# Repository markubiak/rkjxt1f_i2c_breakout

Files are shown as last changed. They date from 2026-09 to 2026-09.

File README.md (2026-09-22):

Alps RKJXT1F42001 7-Way Switch and Encoder I2C Breakout
-------------------------------------------------------

I2C breakout for Alps RKJXT1F42001 using Adafruit Seesaw library on the SAMD09.
Schematic is a copy of the I2C "Stemma QT" Rotary Encoder breakout board
(product 4991), though the NeoPixel and 2x STEMMA QT (JST SH 4-pin) connectors
had to be dropped due to layout constraints. The RKJXT1F is a significantly
larger through-hole device than the rotary encoder and the Stemma QT connectors
simply would not fit in their original locations. However, identical board
shape (1in x 1in) and mounting holes were retained. Due to an oversight, the
pin ordering in the through-hole connection was flipped from the reference
design.

Pins were kept the same as the reference design, so the firmware built on main
branch of adafruit/seesaw works laregly correctly. There is a difference in how
the RKJXT1F handles the rotary encoding compared to typical encoders, so a fork
of the seesaw library is pushed and pending merge back to main. With the
updated firmware, the I2C protocol works as intended. The GPIO Seesaw registers
can be used for the new A/B/C/D pins.

| Direction | GPIO Number |
|---|---|
| A | 16 |
| B | 17 |
| C | 7 |
| D | 2 |
| PUSH | 24 |

The logic to handle the directions is simple enough to not require integration
into the seesaw library. Per the RKJXT1F datasheet, when PUSH goes active
(low), check if any of A/B/C/D are also active (low). If so, it's a directional
press. Else, it was a PUSH.

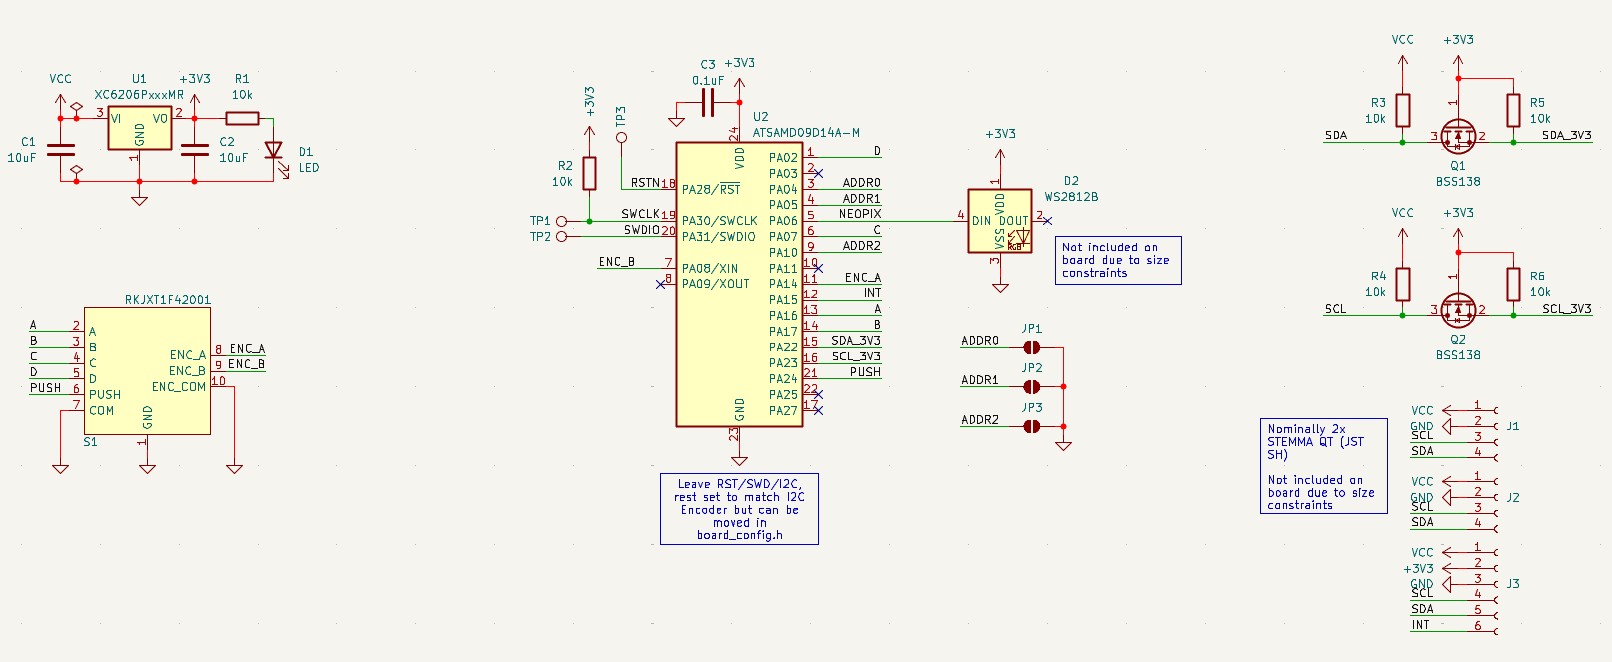
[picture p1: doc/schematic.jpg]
Schematic


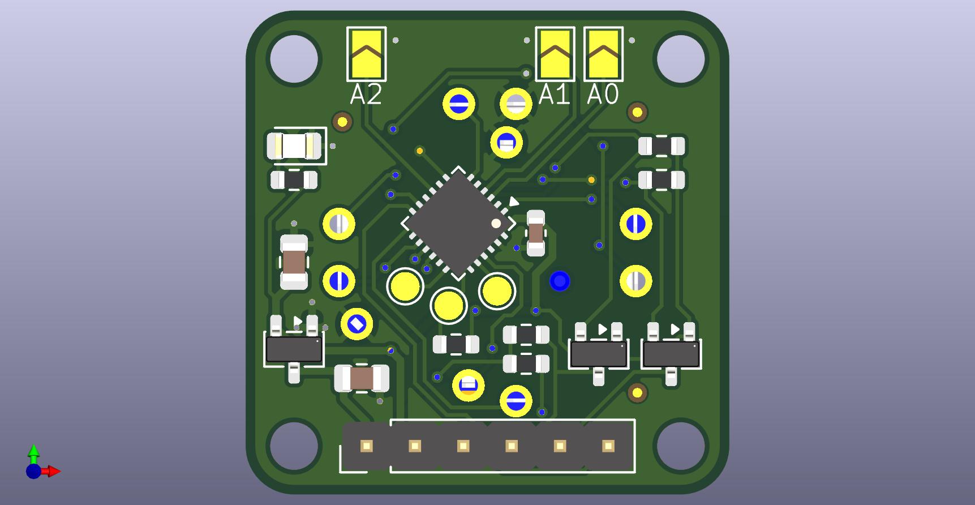
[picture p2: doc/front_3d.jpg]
Front 3D


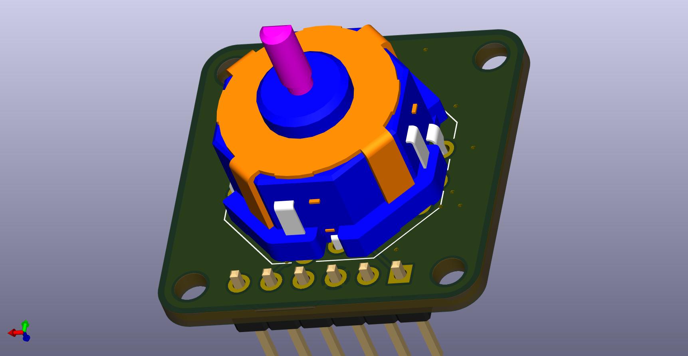
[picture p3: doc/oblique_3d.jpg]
Oblique 3D


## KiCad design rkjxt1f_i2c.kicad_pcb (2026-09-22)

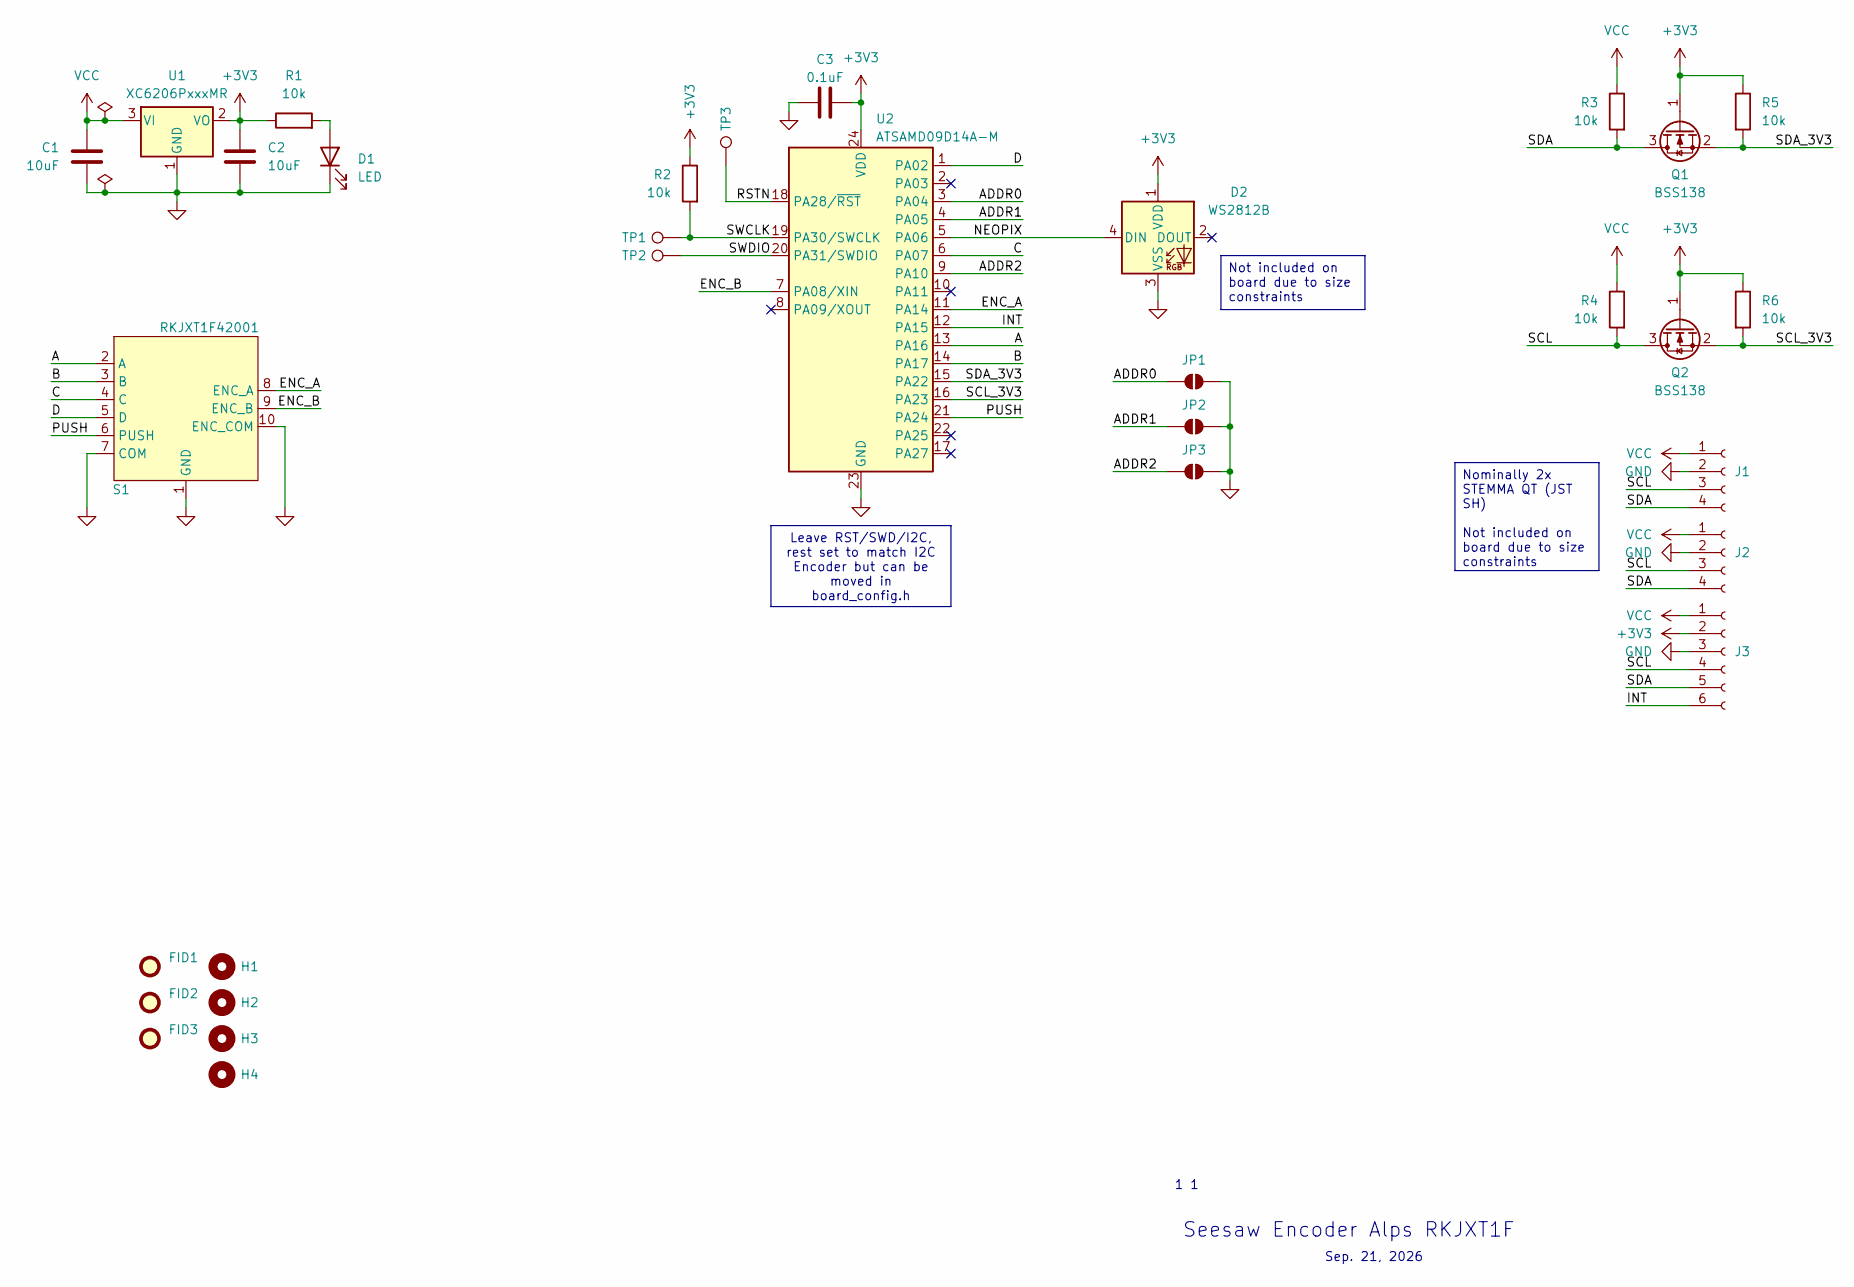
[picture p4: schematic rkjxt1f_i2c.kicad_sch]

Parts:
C1, C2: 10uF; C_0805_2012Metric
C3: 0.1uF; C_0603_1608Metric
D1: LED; LED_0805_2012Metric
D2: WS2812B; LED_WS2812B_PLCC4_5.0x5.0mm_P3.2mm
FID1, FID2, FID3: Fiducial; Fiducial_0.5mm_Mask1mm
H1, H2, H3, H4: MountingHole_Pad; MountingHole_2.5mm
J1, J2: Conn_01x04_Socket; JST_SH_BM04B-SRSS-TB_1x04-1MP_P1.00mm_Vertical
J3: Conn_01x06_Socket; PinHeader_1x06_P2.54mm_Vertical
JP1: A0; SolderJumper-2_P1.3mm_Open_TrianglePad1.0x1.5mm
JP2: A1; SolderJumper-2_P1.3mm_Open_TrianglePad1.0x1.5mm
JP3: A2; SolderJumper-2_P1.3mm_Open_TrianglePad1.0x1.5mm
Q1, Q2: BSS138; SOT-23
R1, R2, R3, R4, R5, R6: 10k; R_0603_1608Metric
S1: RKJXT1F42001
TP1, TP2, TP3: TestPoint; TestPoint_Pad_D1.5mm
U1: XC6206PxxxMR; SOT-23-3
U2: ATSAMD09D14A-M; QFN-24-1EP_4x4mm_P0.5mm_EP2.6x2.6mm

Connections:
+3V3: C2.1, C3.2, D2.1 (VDD), J3.2, Q1.1 (G), Q2.1 (G), R1.1, R2.1, R5.1, R6.1, U1.2 (VO), U2.24 (VDD)
/A: S1.2 (A), U2.13 (PA16)
/ADDR0: JP1.1 (A), U2.3 (PA04)
/ADDR1: JP2.1 (A), U2.4 (PA05)
/ADDR2: JP3.1 (A), U2.9 (PA10)
/B: S1.3 (B), U2.14 (PA17)
/C: S1.4 (C), U2.6 (PA07)
/D: S1.5 (D), U2.1 (PA02)
/ENC_A: S1.8 (ENC_A), U2.11 (PA14)
/ENC_B: S1.9 (ENC_B), U2.7 (PA08/XIN)
/INT: J3.6, U2.12 (PA15)
/NEOPIX: D2.4 (DIN), U2.5 (PA06)
/PUSH: S1.6 (PUSH), U2.21 (PA24)
/RSTN: TP3.1, U2.18 (PA28/~RST)
/SCL: J1.3, J2.3, J3.4, Q2.3 (D), R4.2
/SCL_3V3: Q2.2 (S), R6.2, U2.16 (PA23)
/SDA: J1.4, J2.4, J3.5, Q1.3 (D), R3.2
/SDA_3V3: Q1.2 (S), R5.2, U2.15 (PA22)
/SWCLK: R2.2, TP1.1, U2.19 (PA30/SWCLK)
/SWDIO: TP2.1, U2.20 (PA31/SWDIO)
GND: C1.2, C2.2, C3.1, D1.1 (K), D2.3 (VSS), J1.2, J2.2, J3.3, JP1.2 (B), JP2.2 (B), JP3.2 (B), S1.1 (GND), S1.7 (COM), S1.10 (ENC_COM), U1.1 (GND), U2.23 (GND), U2.25
unnamed: D1.2 (A), R1.2
VCC: C1.1, J1.1, J2.1, J3.1, R3.1, R4.1, U1.3 (VI)

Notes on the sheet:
1 1
Sep. 21, 2026
Seesaw Encoder Alps RKJXT1F
Leave RST/SWD/I2C, rest set to match I2C Encoder but can be moved in board_config.h
Not included on board due to size constraints
Nominally 2x STEMMA QT (JST SH) Not included on board due to size constraints

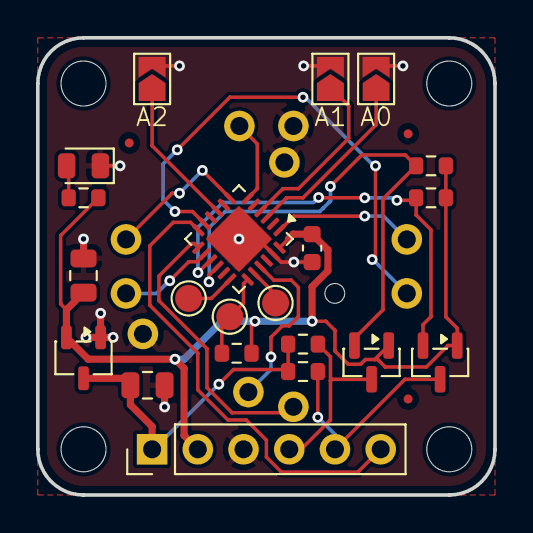
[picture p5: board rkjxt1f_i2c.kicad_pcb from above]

Board: 2 copper layers, 25.4 x 25.4 mm, 29 parts (1 on the bottom side), 22 nets.

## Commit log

2026-09-22 Initial release of RKJXT1F42001 I2C breakout, tested working but missing some QoL features like useful silkscreen, Stemma QT headers and programming port.
    [rkjxt1f_i2c.kicad_pcb, rkjxt1f_i2c.kicad_sch]
2026-09-22 Add pictures of schematic and 3D view.
